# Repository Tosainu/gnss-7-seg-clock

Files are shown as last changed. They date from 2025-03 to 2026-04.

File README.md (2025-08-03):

# GNSS Seven-segment Clock

GNSS-powered, seven-segment table clock.



https://github.com/user-attachments/assets/9b2d0560-d879-4ddb-b99d-07a6e9839360

Full video: https://www.youtube.com/watch?v=Y1P_iDvq4bk

## Firmware

### Usage

Pre-build firmware files are available on the [release page](https://github.com/Tosainu/gnss-7-seg-clock/releases). Thanks to the RP2040 Bootrom, flashing the firmware requires no special tool. Connect the board to the PC using the USB-C cable, while holding the BOOT button (`SW2`). Once the `RPI-RP2` drive appears on the PC, copy `gnss-7-seg-clock.uf2` there. The board will automatically be rebooted as soon as it finishes writing to Flash.

- The board displays `--.--.--` until it obtains the time information.
- Press `SW3` to change the display contents:
    1. Time: `hh.mm.ss`
    2. Date: `YY.MM.DD`
    3. Configuring time zone (time offset): `[-]hh.mm`
        - `SW4`: + 30 min
        - `SW5`: - 30 min

### Build

The firmware is written in the [Rust][rust] programming language with the [Embassy][embassy] framework. In order to build the firmware, you first need to prepare the Rust toolchain. Please refer to the [official guide][rustup].

Next, install the linker helper [`flip-link`][flip-link]. Alternatively, remove [this line](https://github.com/Tosainu/gnss-7-seg-clock/blob/446c9426d9386b7eddf7218308c7567423a233c5/.cargo/config.toml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) to use the default linker.

    $ cargo install --locked flip-link

Lastly, run the command below to build the firmware. You can find the ELF file `./target/thumbv6m-none-eabi/release/gnss-7-seg-clock` afterward.

    $ cargo build --release

If the debug probe is attached to the board and [probe-rs][probe-rs] is installed on your PC, `cargo run` can be used to load firmware to the board.

    $ cargo run --release
    
    # to run test apps in crates/gnss-7-seg-clock/examples/
    $ cargo run --release --example gnss-uart-pipe

## Schematic and PCB

> [!IMPORTANT]
> I'm new to circuits and PCB designs. Any feedback and advice are welcome! (✿ゝ◡╹)ノ

I designed the Rev.A board with KiCad v8.0.8 (Linux/macOS) and their official libraries. You can find the KiCad project files in the [`hardware/`](./hardware/) directory. You can also find the rendered schematic (PDF) and Gerber files on the [release page](https://github.com/Tosainu/gnss-7-seg-clock/releases/tag/hardware%2Frev-a).




<sub>
Please do not take a close look at 43-44 pins of RP2040! (ignorable solder bridge)
</sub>

### Parts

> [!NOTE]
> Tolerances were set by just referring to several existing designs. Some of them might be insufficient or overkill.

| Reference | Value | Parts | Qty |
| --- | --- | --- | --: |
| `C1`, `C2`, `C4-C10`, `C14`, `C17-C19` | MLCC, 0.1uF, 10%, 6.3V, X5R, M1005 | | 13 |
| `C3`, `C11` | MLCC, 1uF, 20%, 6.3V, X5R, M1005 | | 2 |
| [`C12`, `C13`](#ldo-and-capacitors) | MLCC, 10uF, 10%, 6.3V, X7R, M2012 | | 2 |
| `C15`, `C16` | MLCC, 15pF, 5%, 50V, C0G/NP0, M1005 | | 2 |
| [`C20`](#rf-circuitry-for-max-m10s) | MLCC, 10000pF, 10%, 16V, X7R, M1005 | | 1 |
| [`C21`](#rf-circuitry-for-max-m10s) | MLCC, 47pF, 5%, 50V, C0G/NP0, M1005 | | 1 |
| [`D1`](#rf-circuitry-for-max-m10s) | Bidirectional TVS, M1005 | [Littelfuse PESD0402-140][PESD0402-140] | 1 |
| `D2-D7` | LED, M1005 | | 6 |
| `J1` | USB-C Receptacle | [GCT USB4105-GF-A](https://gct.co/connector/usb4105) | 1 |
| `J2` | SMA Receptacle, Edge Mount | [Molex 732511153][732511153] | 1 |
| `J3` | Pin header, 01x03, P2.54 mm | | 1 |
| [`L1`](#rf-circuitry-for-max-m10s) | Inductor, 27nH, 5%, M1005 | [Murata LQG15HS27NJ02D][LQG15HS27NJ02D] | 1 |
| [`R1-R3`](#driving-seven-segment-leds-with-fewer-pins) | Resistor, 2.2kOhm, 1%, 1/16W, M1005 | | 3 |
| `R4`, `R5`, `R12`, `R14-R16` | Resistor, 10kOhm, 1%, 1/16W, M1005 | | 6 |
| `R6`, `R7` | Resistor, 5.1kOhm, 1%, 1/16W, M1005 | | 2 |
| `R8`, `R9` | Resistor, 27Ohm, 1%, 1/16W, M1005 | | 2 |
| `R10`, `R13` | Resistor, 1kOhm, 1%, 1/16W, M1005 | | 2 |
| [`R11`](#rf-circuitry-for-max-m10s) | Resistor, 10Ohm, 5%, 1/4W, M1005 | | 1 |
| `R17-R22` | Resistor, 470Ohm, 1%, 1/16W, M1005 | | 6 |
| `SW1-SW5` | Tactile Switch | [C&K PTS810][PTS810] | 5 |
| [`U1-U6`](#seven-segment-leds) | 7-segment LED, Common-Anode, 3.81 mm | | 6 |
| [`U7-U9`](#driving-seven-segment-leds-with-fewer-pins) | 16-ch LED sink driver, SOIC-24W | [TI TLC5925IDWR][TLC5925] | 3 |
| `U10` | MCU | [Raspberry Pi RP2040][RP2040] | 1 |
| [`U11`](#ldo-and-capacitors) | LDO, 3.3V, 500 mA, SOT-23-5 | [TI TLV75533PDBVR][TLV755P] | 1 |
| `U12` | SQPI NOR Flash, 32M-bit, SOIC-8 | [Winbond W25Q32JVSS][W25Q32JV] | 1 |
| `U13` | GNSS Receiver | [u-blox MAX-M10S][MAX-M10] | 1 |
| `Y1` | Crystal, 12MHz | [Abracon ABM8-272-T3][ABM8-272-T3] | 1 |
| | GNSS Active Antenna | [u-blox ANN-MB5][ANN-MB5] | 1 |

### Seven-segment LEDs

`U1-U6` are seven-segment LEDs, the essential components in this design. While selecting them, I was surprised about the poor availability of seven-segment LEDs, especially the larger models (> 1″). I wanted to use [Kingbright SA15-11GWA][SA15-11GWA] initially. However, due to the availability and price, I selected [WENRUN LSD150BAG-101][LSD150BAG-101], even though I had to use a different store from other parts.

Unfortunately, LSD150BAG-101 is not a drop-in replacement for SA15-11GWA. They have a different pitch for the vertical direction: 40.64mm (SA15-11GWA) and 40.00mm (LSD150BAG-101). Since I wanted to have some flexibility in the design, I made the footprint that uses the oval pad so that can use both types of seven-segment LEDs.

footprint-7-seg

The forward voltage also has to be taken into account for `U1-U6`. Vf should be smaller than the USB VBUS. For instance, high-luminance types are not suitable in general.

### Driving Seven-segment LEDs with Fewer Pins

`U7`, `U8`, and `U9` are 16-ch shift registers specialized for the LED, [TI TLC5925IDWR](TLC5925). Thanks to this three-cascading configuration, it can drive six seven-segment LEDs (48x LED segments) only by five pins.

TLC5925 determines the output currents based on an external resistor between the `R-EXT` pin and `GND`. `R1`, `R2`, and `R3` are the current-set resistors for `U7`, `U8`, and `U9` respectively. With the 2.2kOhm resistor, the output would be (1.21 / 2,200) \* 18  = 9.9mA.

### LDO and Capacitors

`U11` is the 3.3V LDO, [TI TLV75533PDBVR](TLV755P) (TLV755P-series). I'm hoping it works nicely with an AC adapter/wall charger as well as a PC because of its good PSRR in wide-range frequencies.

`C12` and `C13` are the input and output capacitors for the LDO. According to the datasheet, TLV755P requires a 1uF+ input capacitor and a 0.47uF+ output capacitor while considering the DC bias characteristics of a capacitor. Based on this, I selected 10uF/6.3V MLCC.

### RF Circuitry for MAX-M10S

[sparkfun/SparkFun\_u-blox\_MAX-M10S][SparkFun-MAX-M10S] is very good material as well as the MAX-M10S Integration manual. For the RF part, I imitated SparkFun's board and filled in parts values based on the reference design mentioned in the integration manual. Here are the parts correspondences between this board and the MAX-M10S reference design:

| This board | Reference design | Use |
| --- | --- | --- |
| `C20` | `C14` |  RF Bias-T Capacitor |
| `C21` | `C18` | DC Block Capacitor[^dc-block-cap] |
| `L1` | `L3` | RF Bias-T Inductor |
| `R11` | `R8` | Antenna supervisor current limiter/shunt resistor |

`D1` is the ESD-protection TVS which is only in the SparkFun's board. Since I have no confidence in finding compatible parts, I used the same TVS [Littelfuse PESD0402-140][PESD0402-140] in this design.

[^dc-block-cap]: Apparently, this capacitor can be removed as my design doesn't have an external SAW filter. The built-in DC-block capacitor of the module is sufficient.

## Special Thanks - PCBWay

I would like to say a special thank you to [PCBWay](https://www.pcbway.com/) for reaching out and sponsoring my project. As part of the sponsorship, I had the opportunity to try their PCBA service. Overall I am very satisfied with the service and quality of the PCBs. Especially,

- Swift and kind support
    - I was surprised that they reviewed my design files very quickly and gave me a reply after about an hour from the order.
- Numerous customization options for PCB manufacturing
- Help Center
    - There are how-to specialized for KiCad such as [_"How to Generate Gerber and Drill Files in KiCad 8.0?"_](https://www.pcbway.com/helpcenter/generate_gerber/Generate_Gerber_file_from_Kicad.html) and [_"Generate Position File Centroid File(pick place) in Kicad"_](https://www.pcbway.com/helpcenter/design_instruction/Generate_Position_File_in_Kicad.html). They were very helpful when I generate design files for the order.
- Quality of PCBs
    - The board has RP2040 which is the 0.20 mm pitch IC but there were no major issues. One thing to note is the soldermask color: green would be the only choice for such boards according to their explanations and the document [_"Soldermask Issues - Soldermask bridge"_](https://www.pcbway.com/helpcenter/soldermask_issues/Soldermask_bridge.html).

250316-133125-DSC_8347

Note that I made some changes from the Rev.A design for this order, such as changing footprints to a non-HandSolder variant. If you're interested in about the design files I used to order, please refer to the [Rev.A2 release](https://github.com/Tosainu/gnss-7-seg-clock/releases/tag/hardware%2Frev-a2).

## License

The project is licensed under the [MIT](./LICENSE) license unless otherwise stated.

PCD design files, specifically the files under the [`hardware/`](./hardware/) directory are licensed under the [CC BY-SA 4.0](https://creativecommons.org/licenses/by-sa/4.0/) license. Please note that:
- Footprint files described below are made based on the [KiCad Footprint Libraries](https://gitlab.com/kicad/libraries/kicad-footprints) which is licensed under the [CC-BY-SA 4.0 license with exceptions](https://gitlab.com/kicad/libraries/kicad-footprints/-/blob/8.0.8/LICENSE.md?ref_type=tags).
    - [`Display_7Segment_1.5inch_P2.45mm.kicad_mod`](./hardware/gnss-7-seg-clock.pretty/Display_7Segment_1.5inch_P2.45mm.kicad_mod)
    - [`QFN-56-1EP_7x7mm_P0.4mm_EP3.2x3.2mm_HandSolder.kicad_mod`](./hardware/gnss-7-seg-clock.pretty/QFN-56-1EP_7x7mm_P0.4mm_EP3.2x3.2mm_HandSolder.kicad_mod)
    - [`SW_SPST_PTS810_HandSolder.kicad_mod`](./hardware/gnss-7-seg-clock.pretty/SW_SPST_PTS810_HandSolder.kicad_mod)
    - [`USB_C_Receptacle_GCT_USB4105-xx-A_16P_TopMnt_Horizontal_HandSolder.kicad_mod`](./hardware/gnss-7-seg-clock.pretty/USB_C_Receptacle_GCT_USB4105-xx-A_16P_TopMnt_Horizontal_HandSolder.kicad_mod)
- 3D model of ublox MAX module [`MAX (STEP-AP214).STEP`](./hardware/3d_models/MAX%20(STEP-AP214).STEP) is copied from [u-blox/3D-Step-Models-Library@92ce6ba0](https://github.com/u-blox/3D-Step-Models-Library/tree/92ce6ba04a1dacdbec4c5b9e0c032d87bb4d9fc0).

    > Copyright (C) u-blox
    >
    > u-blox reserves all rights in this deliverable (documentation, software, etc., hereafter “Deliverable”).
    >
    > u-blox grants you the right to use, copy, modify and distribute the Deliverable provided hereunder for any purpose without fee.
    >
    > THIS DELIVERABLE IS BEING PROVIDED "AS IS", WITHOUT ANY EXPRESS OR IMPLIED WARRANTY. IN PARTICULAR, NEITHER THE AUTHOR NOR U-BLOX MAKES ANY REPRESENTATION OR WARRANTY OF ANY KIND CONCERNING THE MERCHANTABILITY OF THIS DELIVERABLE OR ITS FITNESS FOR ANY PARTICULAR PURPOSE.
    >
    > In case you provide us a feedback or make a contribution in the form of a further development of the Deliverable (“Contribution”), u-blox will have the same rights as granted to you, namely to use, copy, modify and distribute the Contribution provided to us for any purpose without fee.

- Circuits around the MAX-M10S module on the schematic are made based on [sparkfun/SparkFun\_u-blox\_MAX-M10S][SparkFun-MAX-M10S] which is licensed under the [CC BY-SA 4.0](https://github.com/sparkfun/SparkFun_u-blox_MAX-M10S/blob/8e937406ba0f21e3afc8ca20ddeb06b088023951/LICENSE.md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) license for the hardware part.

This project is inspired by [Kello version 4](http://kair.us/projects/clock/v4/index.html).

[rust]: https://www.rust-lang.org/
[rustup]: https://www.rust-lang.org/tools/install
[embassy]: https://embassy.dev/
[flip-link]: https://github.com/knurling-rs/flip-link
[probe-rs]: https://probe.rs/

[RP2040]: https://www.raspberrypi.com/products/rp2040/
[LQG15HS27NJ02D]: https://www.murata.com/en-global/products/productdetail?partno=LQG15HS27NJ02%23
[LSD150BAG-101]: https://www.tme.eu/en/details/lsd150bag-101/7-segment-led-displays/wenrun/lsd150bag-101-01/
[PESD0402-140]: https://www.littelfuse.com/products/overvoltage-protection/polymer-esd-suppressors/pesd-protection-device/pesd/pesd0402-140
[PTS810]: https://www.ckswitches.com/products/switches/product-details/Tactile/PTS810/
[TLC5925]: https://www.ti.com/product/TLC5925
[TLV755P]: https://www.ti.com/product/TLV755P
[W25Q32JV]: https://www.winbond.com/hq/product/code-storage-flash-memory/serial-nor-flash/?__locale=en&partNo=W25Q32JV
[732511153]: https://www.molex.com/en-us/products/part-detail/732511153
[USB4105]: https://gct.co/connector/usb4105
[ABM8-272-T3]: https://abracon.com/datasheets/ABM8-272-T3.pdf
[ANN-MB5]: https://www.u-blox.com/en/product/ann-mb5-antenna
[MAX-M10]: https://www.u-blox.com/en/product/max-m10-series
[SA15-11GWA]: https://www.kingbrightusa.com/product.asp?catalog_name=LED&product_id=SA15-11GWA

[SparkFun-MAX-M10S]: https://github.com/sparkfun/SparkFun_u-blox_MAX-M10S

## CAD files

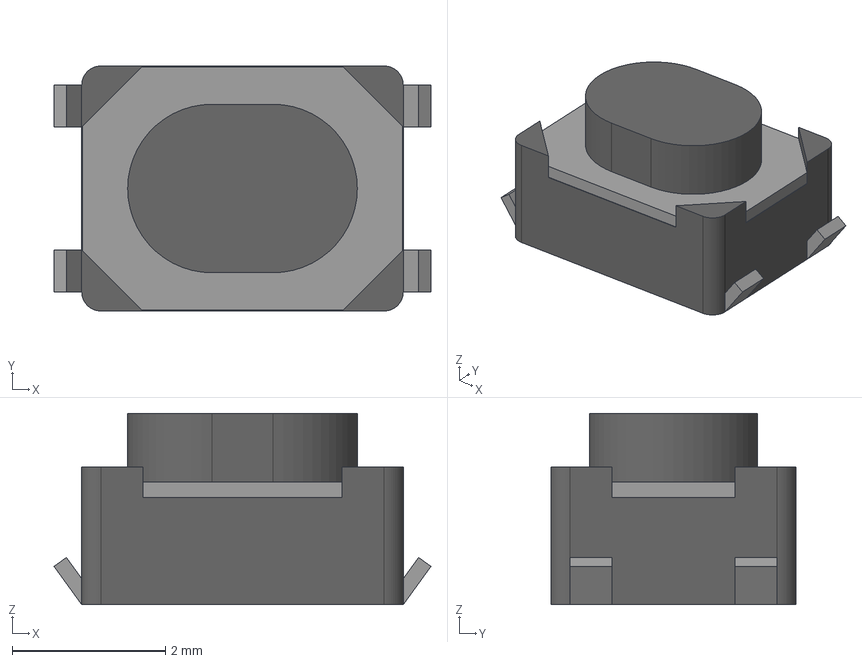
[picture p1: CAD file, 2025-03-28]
hardware/3d_models/PTS810.step
4.92 x 3.20 x 2.50 mm
Array (mirrored)
Pin x 2

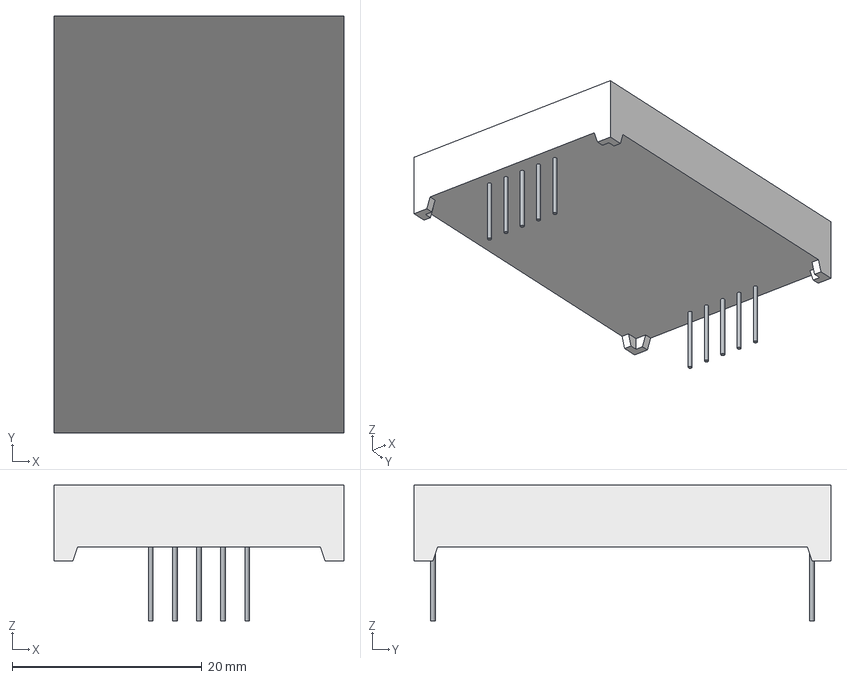
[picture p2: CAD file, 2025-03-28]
hardware/3d_models/LSD150BAG-101.step
30.6 x 44.0 x 14.3 mm
Plane
Plane001

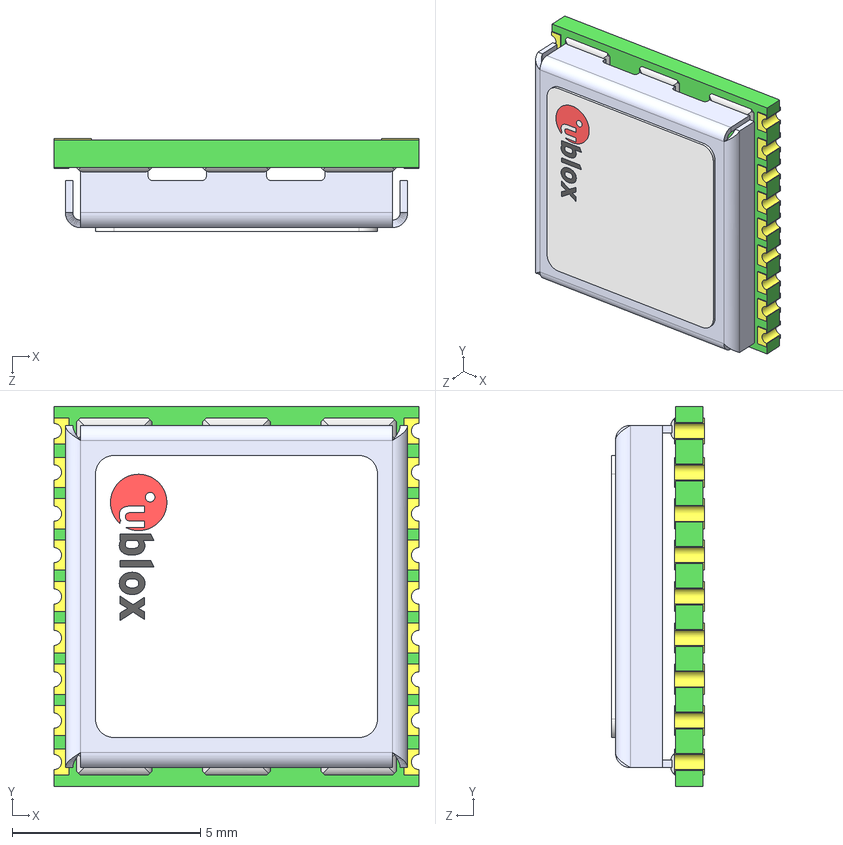
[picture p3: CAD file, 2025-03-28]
hardware/3d_models/MAX (STEP-AP214).STEP
9.70 x 10.1 x 2.47 mm
u-blox_MAX_label_Default
Shield
MAX_PCB

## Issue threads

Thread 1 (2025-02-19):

Strange things with RF

MuratovAS, 2025-02-19:
You clearly have problems with the RF cascade.
1. You put C21 (`DC BLOCK`), but for your `ublox` it is probably not required (check)
2. C20 and L1 should form a contour. Preventing leakage of a useful signal in power

P.S. I am not a radio engineer, I specialize in digital technique. So check my words.

A few schemes that I use as a reference:
https://github.com/dizcza/neo_m8p_board/blob/master/schematics.pdf
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

https://github.com/mlab-modules/GPS02
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

https://github.com/sparkfun/SparkFun_u-blox_MAX-M10S/blob/main/Hardware/SparkFun%20u-blox%20GNSS%20MAX-M10S.pdf
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

MuratovAS, 2025-02-19:
I build my cascade like this:
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

P.S. In a month I will have information about the quality of such a scheme

Tosainu, 2025-02-19:
Thank you for the information. That should be helpful for me since I'm not an RF expert or even an electronics engineer.

Regarding the DC BLOCK capacitor, I placed this capacitor because of the reference design mentioned in the MAX-M10S Integration Manual. I actually realized that most existing designs do not place such capacitors.
https://www.u-blox.com/sites/default/files/MAX-M10S_IntegrationManual_UBX-20053088.pdf

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

> 2. C20 and L1 should form a contour. Preventing leakage of a useful signal in power

Sorry but could you tell me a little more details on this point? I could not even find much difference with the designs you mentioned.

---

PS: I've just finished the first prototyping and I'm working on developing the firmware now. I verified that it could get a 3D fix at least. As you pointed out, there might be room to improve the signal quality though.

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

MuratovAS, 2025-02-20:
1. I found confirmation in the document.

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
https://content.u-blox.com/sites/default/files/MAX-M10S_DataSheet_UBX-20035208.pdf

Tosainu, 2025-02-20:
Thank you. And I might have figured out why Figure 38 has the DC Block capacitor. It's necessary when using an external SAW filter (F1), and needs to be placed in front of the filter.

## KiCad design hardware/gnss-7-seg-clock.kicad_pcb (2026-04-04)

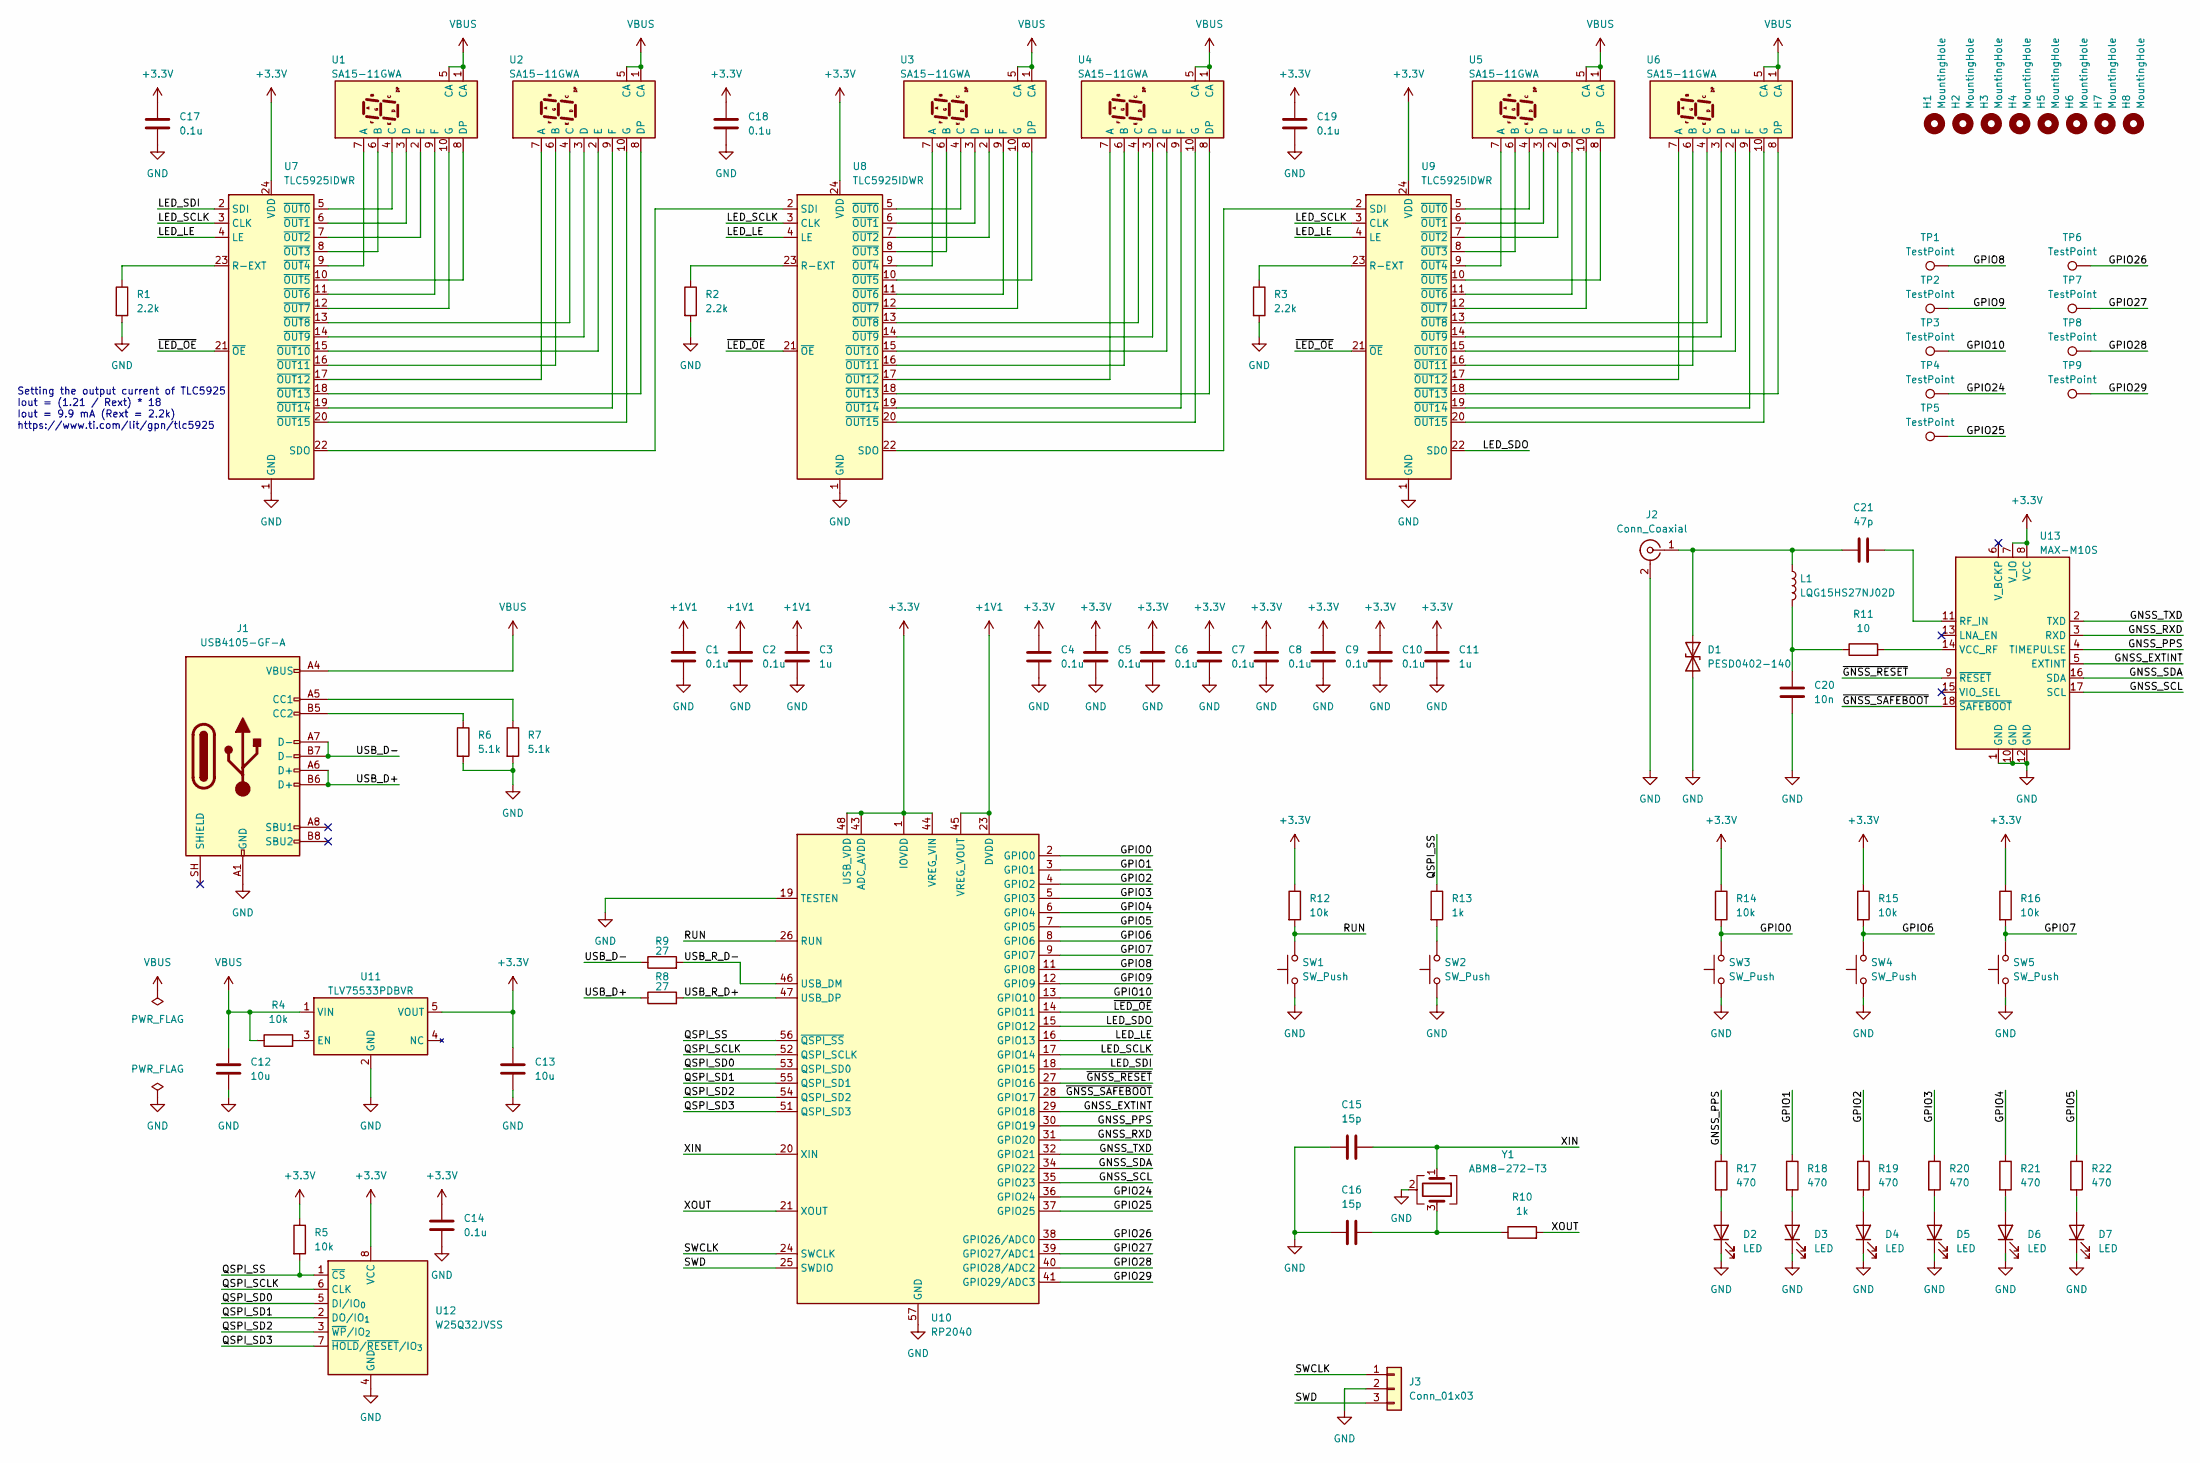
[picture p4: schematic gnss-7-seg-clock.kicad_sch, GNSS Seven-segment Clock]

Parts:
C1, C2, C4, C5, C6, C7, C8, C9, C10, C14, C17, C18, C19: 0.1u; C_0402_1005Metric_Pad0.74x0.62mm_HandSolder
C3, C11: 1u; C_0402_1005Metric_Pad0.74x0.62mm_HandSolder
C12, C13: 10u; C_0805_2012Metric_Pad1.18x1.45mm_HandSolder
C15, C16: 15p; C_0402_1005Metric_Pad0.74x0.62mm_HandSolder
C20: 10n; C_0402_1005Metric_Pad0.74x0.62mm_HandSolder
C21: 47p; C_0402_1005Metric_Pad0.74x0.62mm_HandSolder
D1: PESD0402-140; D_0402_1005Metric_Pad0.77x0.64mm_HandSolder
D2, D3, D4, D5, D6, D7: LED; LED_0402_1005Metric_Pad0.77x0.64mm_HandSolder
H1, H2, H3, H4, H5, H6, H7, H8: MountingHole; MountingHole_3.2mm_M3
J1: USB4105-GF-A; USB_C_Receptacle_GCT_USB4105-xx-A_16P_TopMnt_Horizontal_Han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
J2: Conn_Coaxial; SMA_Molex_73251-1153_EdgeMount_Horizontal
J3: Conn_01x03; PinHeader_1x03_P2.54mm_Vertical
L1: LQG15HS27NJ02D; L_0402_1005Metric_Pad0.77x0.64mm_HandSolder
R1, R2, R3: 2.2k; R_0402_1005Metric_Pad0.72x0.64mm_HandSolder
R4, R5, R12, R14, R15, R16: 10k; R_0402_1005Metric_Pad0.72x0.64mm_HandSolder
R6, R7: 5.1k; R_0402_1005Metric_Pad0.72x0.64mm_HandSolder
R8, R9: 27; R_0402_1005Metric_Pad0.72x0.64mm_HandSolder
R10, R13: 1k; R_0402_1005Metric_Pad0.72x0.64mm_HandSolder
R11: 10; R_0402_1005Metric_Pad0.72x0.64mm_HandSolder
R17, R18, R19, R20, R21, R22: 470; R_0402_1005Metric_Pad0.72x0.64mm_HandSolder
SW1, SW2, SW3, SW4, SW5: SW_Push; SW_SPST_PTS810_HandSolder
TP1, TP2, TP3, TP4, TP5, TP6, TP7, TP8, TP9: TestPoint; TestPoint_Pad_1.0x1.0mm
U1, U2, U3, U4, U5, U6: SA15-11GWA; Display_7Segment_1.5inch_P2.45mm
U7, U8, U9: TLC5925IDWR; SOIC-24W_7.5x15.4mm_P1.27mm
U10: RP2040; QFN-56-1EP_7x7mm_P0.4mm_EP3.2x3.2mm
U11: TLV75533PDBVR; TSOT-23-5_HandSoldering
U12: W25Q32JVSS; SOIC-8_5.3x5.3mm_P1.27mm
U13: MAX-M10S
Y1: ABM8-272-T3; Crystal_SMD_3225-4Pin_3.2x2.5mm_HandSoldering

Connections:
+1V1: C1.1, C2.1, C3.1, U10.23 (DVDD), U10.45 (VREG_VOUT), U10.50 (DVDD)
+3.3V: C4.1, C5.1, C6.1, C7.1, C8.1, C9.1, C10.1, C11.1, C13.1, C14.1, C17.1, C18.1, C19.1, R5.1, R12.1, R14.1, R15.1, R16.1, U7.24 (VDD), U8.24 (VDD), U9.24 (VDD), U10.1 (IOVDD), U10.10 (IOVDD), U10.22 (IOVDD), U10.33 (IOVDD), U10.42 (IOVDD), U10.43 (ADC_AVDD), U10.44 (VREG_VIN), U10.48 (USB_VDD), U10.49 (IOVDD), U11.5 (VOUT), U12.8 (VCC), U13.7 (V_IO), U13.8 (VCC)
/GNSS_EXTINT: U10.29 (GPIO18), U13.5 (EXTINT)
/GNSS_PPS: R17.1, U10.30 (GPIO19), U13.4 (TIMEPULSE)
/GNSS_RXD: U10.31 (GPIO20), U13.3 (RXD)
/GNSS_SCL: U10.35 (GPIO23), U13.17 (SCL)
/GNSS_SDA: U10.34 (GPIO22), U13.16 (SDA)
/GNSS_TXD: U10.32 (GPIO21), U13.2 (TXD)
/GPIO0: R14.2, SW3.2, U10.2 (GPIO0)
/GPIO1: R18.1, U10.3 (GPIO1)
/GPIO2: R19.1, U10.4 (GPIO2)
/GPIO3: R20.1, U10.5 (GPIO3)
/GPIO4: R21.1, U10.6 (GPIO4)
/GPIO5: R22.1, U10.7 (GPIO5)
/GPIO6: R15.2, SW4.2, U10.8 (GPIO6)
/GPIO7: R16.2, SW5.2, U10.9 (GPIO7)
/GPIO8: TP1.1, U10.11 (GPIO8)
/GPIO9: TP2.1, U10.12 (GPIO9)
/GPIO10: TP3.1, U10.13 (GPIO10)
/GPIO24: TP4.1, U10.36 (GPIO24)
/GPIO25: TP5.1, U10.37 (GPIO25)
/GPIO26: TP6.1, U10.38 (GPIO26/ADC0)
/GPIO27: TP7.1, U10.39 (GPIO27/ADC1)
/GPIO28: TP8.1, U10.40 (GPIO28/ADC2)
/GPIO29: TP9.1, U10.41 (GPIO29/ADC3)
/LED_LE: U7.4 (LE), U8.4 (LE), U9.4 (LE), U10.16 (GPIO13)
/LED_SCLK: U7.3 (CLK), U8.3 (CLK), U9.3 (CLK), U10.17 (GPIO14)
/LED_SDI: U7.2 (SDI), U10.18 (GPIO15)
/LED_SDO: U9.22 (SDO), U10.15 (GPIO12)
/QSPI_SCLK: U10.52 (QSPI_SCLK), U12.6 (CLK)
/QSPI_SD0: U10.53 (QSPI_SD0), U12.5 (DI/IO_{0})
/QSPI_SD1: U10.55 (QSPI_SD1), U12.2 (DO/IO_{1})
/QSPI_SD2: U10.54 (QSPI_SD2), U12.3 (~WP/IO_{2})
/QSPI_SD3: U10.51 (QSPI_SD3), U12.7 (~HOLD/~RESET/IO_{3})
/QSPI_SS: R5.2, R13.1, U10.56 (~QSPI_SS), U12.1 (~CS)
/RUN: R12.2, SW1.2, U10.26 (RUN)
/SWCLK: J3.1, U10.24 (SWCLK)
/SWD: J3.3, U10.25 (SWDIO)
/USB_D+: J1.A6 (D+), J1.B6 (D+), R8.1
/USB_D-: J1.A7 (D-), J1.B7 (D-), R9.1
/USB_R_D+: R8.2, U10.47 (USB_DP)
/USB_R_D-: R9.2, U10.46 (USB_DM)
/XIN: C15.2, U10.20 (XIN), Y1.1
/XOUT: R10.2, U10.21 (XOUT)
/~GNSS_RESET: U10.27 (GPIO16), U13.9 (~RESET)
/~GNSS_SAFEBOOT: U10.28 (GPIO17), U13.18 (~SAFEBOOT)
/~LED_OE: U7.21 (~OE), U8.21 (~OE), U9.21 (~OE), U10.14 (GPIO11)
GND: C1.2, C2.2, C3.2, C4.2, C5.2, C6.2, C7.2, C8.2, C9.2, C10.2, C11.2, C12.2, C13.2, C14.2, C15.1, C16.1, C17.2, C18.2, C19.2, C20.2, D1.2 (A2), D2.1 (K), D3.1 (K), D4.1 (K), D5.1 (K), D6.1 (K), D7.1 (K), J1.A1 (GND), J1.A12 (GND), J1.B1 (GND), J1.B12 (GND), J2.2 (Ext), J3.2, R1.2, R2.2, R3.2, R6.2, R7.2, SW1.1, SW2.1, SW3.1, SW4.1, SW5.1, U7.1 (GND), U8.1 (GND), U9.1 (GND), U10.19 (TESTEN), U10.57 (GND), U11.2 (GND), U12.4 (GND), U13.1 (GND), U13.10 (GND), U13.12 (GND), Y1.2 (G), Y1.4 (G)
unnamed: C16.2, R10.1, Y1.3
unnamed: C20.1, L1.2, R11.1
unnamed: C21.1, D1.1 (A1), J2.1 (In), L1.1
unnamed: D2.2 (A), R17.2
unnamed: D3.2 (A), R18.2
unnamed: D4.2 (A), R19.2
unnamed: D5.2 (A), R20.2
unnamed: D6.2 (A), R21.2
unnamed: D7.2 (A), R22.2
unnamed: J1.A5 (CC1), R7.1
unnamed: J1.B5 (CC2), R6.1
unnamed: R13.2, SW2.2
unnamed: U1.7 (A), U7.9 (~OUT4)
unnamed: U1.6 (B), U7.8 (~OUT3)
unnamed: U1.4 (C), U7.5 (~OUT0)
unnamed: U1.3 (D), U7.6 (~OUT1)
unnamed: U1.8 (DP), U7.10 (~OUT5)
unnamed: U1.2 (E), U7.7 (~OUT2)
unnamed: U1.9 (F), U7.11 (~OUT6)
unnamed: U1.10 (G), U7.12 (~OUT7)
unnamed: U2.7 (A), U7.17 (~OUT12)
unnamed: U2.6 (B), U7.16 (~OUT11)
unnamed: U2.4 (C), U7.13 (~OUT8)
unnamed: U2.3 (D), U7.14 (~OUT9)
unnamed: U2.8 (DP), U7.18 (~OUT13)
unnamed: U2.2 (E), U7.15 (~OUT10)
unnamed: U2.9 (F), U7.19 (~OUT14)
unnamed: U2.10 (G), U7.20 (~OUT15)
unnamed: U3.7 (A), U8.9 (~OUT4)
unnamed: U3.6 (B), U8.8 (~OUT3)
unnamed: U3.4 (C), U8.5 (~OUT0)
unnamed: U3.3 (D), U8.6 (~OUT1)
unnamed: U3.8 (DP), U8.10 (~OUT5)
unnamed: U3.2 (E), U8.7 (~OUT2)
unnamed: U3.9 (F), U8.11 (~OUT6)
unnamed: U3.10 (G), U8.12 (~OUT7)
unnamed: U4.7 (A), U8.17 (~OUT12)
unnamed: U4.6 (B), U8.16 (~OUT11)
unnamed: U4.4 (C), U8.13 (~OUT8)
unnamed: U4.3 (D), U8.14 (~OUT9)
unnamed: U4.8 (DP), U8.18 (~OUT13)
unnamed: U4.2 (E), U8.15 (~OUT10)
unnamed: U4.9 (F), U8.19 (~OUT14)
unnamed: U4.10 (G), U8.20 (~OUT15)
unnamed: U5.7 (A), U9.9 (~OUT4)
unnamed: U5.6 (B), U9.8 (~OUT3)
unnamed: U5.4 (C), U9.5 (~OUT0)
unnamed: U5.3 (D), U9.6 (~OUT1)
unnamed: U5.8 (DP), U9.10 (~OUT5)
unnamed: U5.2 (E), U9.7 (~OUT2)
unnamed: U5.9 (F), U9.11 (~OUT6)
unnamed: U5.10 (G), U9.12 (~OUT7)
unnamed: U6.7 (A), U9.17 (~OUT12)
unnamed: U6.6 (B), U9.16 (~OUT11)
unnamed: U6.4 (C), U9.13 (~OUT8)
unnamed: U6.3 (D), U9.14 (~OUT9)
unnamed: U6.8 (DP), U9.18 (~OUT13)
unnamed: U6.2 (E), U9.15 (~OUT10)
unnamed: U6.9 (F), U9.19 (~OUT14)
unnamed: U6.10 (G), U9.20 (~OUT15)
unnamed: R1.1, U7.23 (R-EXT)
unnamed: U7.22 (SDO), U8.2 (SDI)
unnamed: R2.1, U8.23 (R-EXT)
unnamed: U8.22 (SDO), U9.2 (SDI)
unnamed: R3.1, U9.23 (R-EXT)
unnamed: R4.2, U11.3 (EN)
unnamed: C21.2, U13.11 (RF_IN)
unnamed: R11.2, U13.14 (VCC_RF)
VBUS: C12.1, J1.A4 (VBUS), J1.A9 (VBUS), J1.B4 (VBUS), J1.B9 (VBUS), R4.1, U1.1 (CA), U1.5 (CA), U2.1 (CA), U2.5 (CA), U3.1 (CA), U3.5 (CA), U4.1 (CA), U4.5 (CA), U5.1 (CA), U5.5 (CA), U6.1 (CA), U6.5 (CA), U11.1 (VIN)

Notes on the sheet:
Setting the output current of TLC5925 Iout = (1.21 / Rext) * 18 Iout = 9.9 mA (Rext = 2.2k) https://www.ti.com/lit/gpn/tlc5925

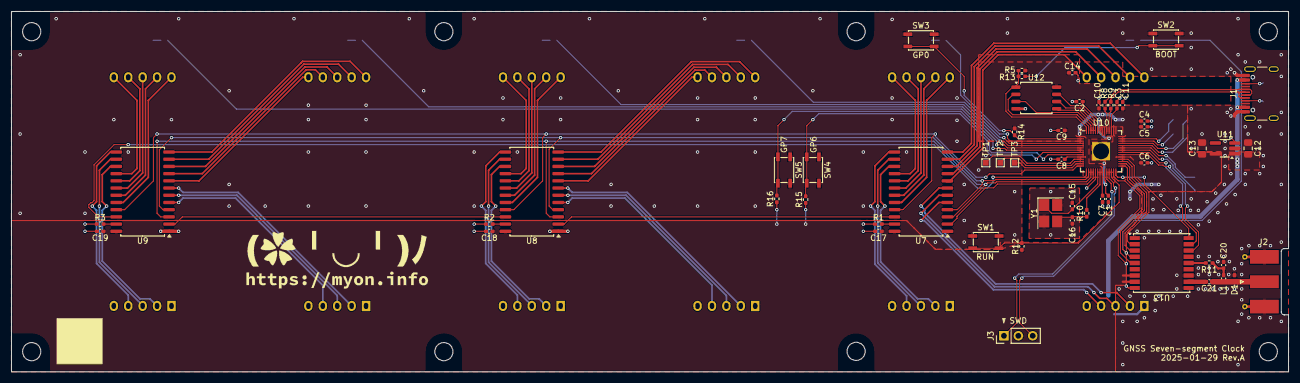
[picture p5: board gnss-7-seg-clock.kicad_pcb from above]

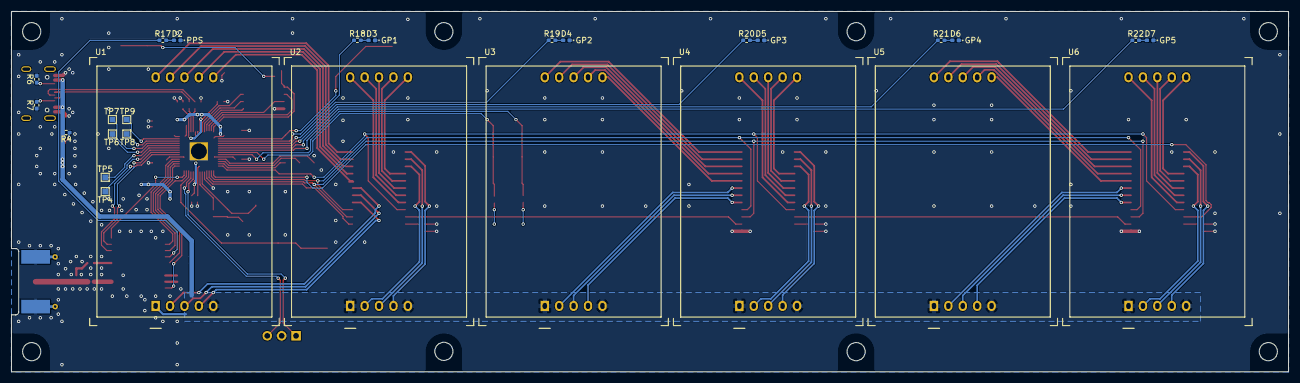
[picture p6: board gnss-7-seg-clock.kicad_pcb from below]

Board: 2 copper layers, 225.0 x 63.5 mm, 90 parts (27 on the bottom side), 117 nets.

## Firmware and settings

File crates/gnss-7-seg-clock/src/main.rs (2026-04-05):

#![no_std]
#![no_main]

use embassy_executor::Spawner;
use embassy_rp::dma;
use embassy_rp::flash;
use embassy_rp::gpio;
use embassy_rp::i2c;
use embassy_rp::peripherals::{DMA_CH0, I2C1, UART1};
use embassy_rp::spi;
use embassy_rp::uart;
use embassy_sync::{
    blocking_mutex::raw::{RawMutex, ThreadModeRawMutex},
    channel::Channel,
};
use static_cell::StaticCell;

use chrono::{Datelike, FixedOffset, NaiveDate, NaiveTime, Timelike};

use gnss_7_seg_clock::{
    display::{self, Display},
    events::*,
    flash::NonVolatileConfig,
    max_m10s::{Event as MaxM10sEvent, MaxM10s},
};

use {defmt_rtt as _, panic_probe as _};

embassy_rp::bind_interrupts!(struct Irqs {
    DMA_IRQ_0 => dma::InterruptHandler<DMA_CH0>;
    I2C1_IRQ => i2c::InterruptHandler<I2C1>;
    UART1_IRQ => uart::BufferedInterruptHandler<UART1>;
});

type MaxM10sEventChannel = Channel<ThreadModeRawMutex, MaxM10sEvent, 8>;

//
//     +- A -+
//     F     B
//     +- G -+
//     E     C
//     +- D -+
//
//    GFpABEDC
const TABLE: [u8; 10] = [
    0b01011111_u8, // '0'
    0b00001001_u8, // '1'
    0b10011110_u8, // '2'
    0b10011011_u8, // '3'
    0b11001001_u8, // '4'
    0b11010011_u8, // '5'
    0b11010111_u8, // '6'
    0b00011001_u8, // '7'
    0b11011111_u8, // '8'
    0b11011011_u8, // '9'
];

#[allow(dead_code)]
const MASK_DP: u8 = 0b00100000;

// "--.--.--"
const PATTERN_NO_TIME: display::Payload = display::Payload([
    0b10000000_u8,
    0b10000000_u8,
    0b10100000_u8,
    0b10000000_u8,
    0b10100000_u8,
    0b10000000_u8,
]);

fn date_to_display_payload(date: NaiveDate) -> display::Payload {
    display::Payload([
        TABLE[date.day() as usize % 10],
        TABLE[date.day() as usize / 10 % 10],
        TABLE[date.month() as usize % 10] | MASK_DP,
        TABLE[date.month() as usize / 10 % 10],
        TABLE[date.year() as usize % 10] | MASK_DP,
        TABLE[date.year() as usize / 10 % 10],
    ])
}

fn time_to_display_payload(time: NaiveTime) -> display::Payload {
    display::Payload([
        TABLE[time.second() as usize % 10],
        TABLE[time.second() as usize / 10 % 10],
        TABLE[time.minute() as usize % 10] | MASK_DP,
        TABLE[time.minute() as usize / 10 % 10],
        TABLE[time.hour() as usize % 10] | MASK_DP,
        TABLE[time.hour() as usize / 10 % 10],
    ])
}

fn u32_to_display_payload(value: u32) -> display::Payload {
    let mut arr = [
        TABLE[value as usize % 10],
        TABLE[value as usize / 10 % 10],
        TABLE[value as usize / 100 % 10],
        TABLE[value as usize / 1000 % 10],
        TABLE[value as usize / 10000 % 10],
        TABLE[value as usize / 100000 % 10],
    ];
    arr[3] |= MASK_DP;
    if value < 100_000 {
        arr[5] = 0;
    }
    if value < 10_000 {
        arr[4] = 0;
    }
    display::Payload(arr)
}

const FLASH_SIZE: usize = 4 * 1024 * 1024; // W25Q32JVSS
const ADDR_OFFSET: u32 = (FLASH_SIZE - flash::ERASE_SIZE) as u32;

#[derive(Copy, Clone, Default, PartialEq, serde::Serialize, serde::Deserialize, defmt::Format)]
struct Config {
    time_zone_secs: i32,
}

impl Config {
    fn time_zone(&self) -> FixedOffset {
        FixedOffset::east_opt(self.time_zone_secs).unwrap()
    }
}

#[derive(Copy, Clone, PartialEq, defmt::Format)]
enum DisplayMode {
    Time,
    Date,
    Velocity,
    ConfigTimeZone,
}

impl DisplayMode {
    fn next_state(&self) -> DisplayMode {
        match self {
            DisplayMode::Time => DisplayMode::Date,
            DisplayMode::Date => DisplayMode::Velocity,
            DisplayMode::Velocity => DisplayMode::ConfigTimeZone,
            DisplayMode::ConfigTimeZone => DisplayMode::Time,
        }
    }
}

#[embassy_executor::main]
async fn main(spawner: Spawner) {
    let p = embassy_rp::init(Default::default());

    defmt::info!("Hello World!");

    let mut nvcfg = NonVolatileConfig::<_, _, FLASH_SIZE, ADDR_OFFSET, 512>::new(p.FLASH);
    let mut cfg: Config = defmt::unwrap!(nvcfg.read_or_default());
    defmt::info!("{}", cfg);

    let sw3 = gpio::Input::new(p.PIN_0, gpio::Pull::None);
    let sw4 = gpio::Input::new(p.PIN_6, gpio::Pull::None);
    let sw5 = gpio::Input::new(p.PIN_7, gpio::Pull::None);

    let mut leds = [
        gpio::Output::new(p.PIN_1, gpio::Level::Low),
        gpio::Output::new(p.PIN_2, gpio::Level::Low),
        gpio::Output::new(p.PIN_3, gpio::Level::Low),
        gpio::Output::new(p.PIN_4, gpio::Level::Low),
        gpio::Output::new(p.PIN_5, gpio::Level::Low),
    ];

    let _spi1_rx = gpio::Input::new(p.PIN_12, gpio::Pull::Down);
    let mut display = Display::new(
        p.SPI1, p.PIN_14, p.PIN_15, p.DMA_CH0, p.PIN_11, p.PIN_13, Irqs,
    );

    display.shift(&PATTERN_NO_TIME).await;
    display.refresh().await;
    display.output(true);

    let _uart1_tx = gpio::Input::new(p.PIN_20, gpio::Pull::Up);
    let mut max_m10s_pps = gpio::Input::new(p.PIN_19, gpio::Pull::Down);
    let max_m10s = {
        static UART1_BUF_RX: StaticCell<[u8; 1024]> = StaticCell::new();
        MaxM10s::new(
            p.UART1,
            p.PIN_21,
            UART1_BUF_RX.init([0; 1024]).as_mut_slice(),
            p.I2C1,
            p.PIN_23,
            p.PIN_22,
            p.PIN_16,
            p.PIN_18,
            Irqs,
        )
    };

    static MAX_M10S_EVENT_CHANNEL: MaxM10sEventChannel = MaxM10sEventChannel::new();

    spawner.spawn(defmt::unwrap!(task_max_m10s(
        max_m10s,
        &MAX_M10S_EVENT_CHANNEL
    )));

    max_m10s_pps.wait_for_low().await;

    let mut mode = DisplayMode::Time;
    let mut es = EventSources::new(
        MAX_M10S_EVENT_CHANNEL.receiver(),
        sw3,
        sw4,
        sw5,
        max_m10s_pps,
    );

    loop {
        defmt::info!("mode: {}", mode);
        set_leds(&mut leds, mode);
        match mode {
            DisplayMode::Time => handle_mode_time(&mut es, &cfg, &mut display).await,
            DisplayMode::Date => handle_mode_date(&mut es, &cfg, &mut display).await,
            DisplayMode::Velocity => handle_mode_velocity(&mut es, &cfg, &mut display).await,
            DisplayMode::ConfigTimeZone => {
                let t = handle_mode_config_time_zone(&mut es, &cfg, &mut display).await;
                if t != cfg.time_zone_secs {
                    cfg.time_zone_secs = t;
                    defmt::unwrap!(nvcfg.write(&cfg));
                }
            }
        }
        mode = mode.next_state();
    }
}

fn set_leds(leds: &mut [gpio::Output<'_>; 5], mode: DisplayMode) {
    let bits = match mode {
        DisplayMode::Time => 0b0_0001_u8,
        DisplayMode::Date => 0b0_0010_u8,
        DisplayMode::Velocity => 0b0_0011_u8,
        DisplayMode::ConfigTimeZone => 0b1_0001_u8,
    };
    leds[0].set_level((bits & 0b1_0000 > 0).into());
    leds[1].set_level((bits & 0b0_1000 > 0).into());
    leds[2].set_level((bits & 0b0_0100 > 0).into());
    leds[3].set_level((bits & 0b0_0010 > 0).into());
    leds[4].set_level((bits & 0b0_0001 > 0).into());
}

async fn handle_mode_time<R: RawMutex, Spi: spi::Instance, const N: usize>(
    es: &mut EventSources<'_, R, N>,
    cfg: &Config,
    display: &mut Display<'_, Spi>,
) {
    if let Some(datetime) = es.datetime {
        let t = datetime + cfg.time_zone();
        display.shift(&time_to_display_payload(t.time())).await;
        display.refresh().await;
        if let Some(datetime_next_pulse) = es.datetime_next_pulse {
            let t_next = datetime_next_pulse + cfg.time_zone();
            display.shift(&time_to_display_payload(t_next.time())).await;
        }
    } else {
        display.shift(&PATTERN_NO_TIME).await;
        display.refresh().await;
    }

    loop {
        match es.wait().await {
            Event::DateTimeAndVelocity { datetime, .. } => {
                if es.datetime_next_pulse.is_none() && datetime.nanosecond() == 0 {
                    let t = datetime + cfg.time_zone();
                    display.shift(&time_to_display_payload(t.time())).await;
                    display.refresh().await;
                }
            }
            Event::DateTimeNextPulse(datetime) => {
                let t = datetime + cfg.time_zone();
                display.shift(&time_to_display_payload(t.time())).await;
            }
            Event::TimePulse => {
                display.refresh().await;
            }
            Event::Sw3Pressed => return,
            _ => (),
        }
    }
}

async fn handle_mode_date<R: RawMutex, Spi: spi::Instance, const N: usize>(
    es: &mut EventSources<'_, R, N>,
    cfg: &Config,
    display: &mut Display<'_, Spi>,
) {
    if let Some(datetime) = es.datetime {
        let t = datetime + cfg.time_zone();
        display.shift(&date_to_display_payload(t.date())).await;
        display.refresh().await;
        if let Some(datetime_next_pulse) = es.datetime_next_pulse {
            let t_next = datetime_next_pulse + cfg.time_zone();
            display.shift(&date_to_display_payload(t_next.date())).await;
        }
    } else {
        display.shift(&PATTERN_NO_TIME).await;
        display.refresh().await;
    }

    loop {
        match es.wait().await {
            Event::DateTimeAndVelocity { datetime, .. } => {
                if es.datetime_next_pulse.is_none() && datetime.nanosecond() == 0 {
                    let t = datetime + cfg.time_zone();
                    display.shift(&date_to_display_payload(t.date())).await;
                    display.refresh().await;
                }
            }
            Event::DateTimeNextPulse(datetime) => {
                let t = datetime + cfg.time_zone();
                display.shift(&date_to_display_payload(t.date())).await;
            }
            Event::TimePulse => {
                display.refresh().await;
            }
            Event::Sw3Pressed => return,
            _ => (),
        }
    }
}

async fn handle_mode_velocity<R: RawMutex, Spi: spi::Instance, const N: usize>(
    es: &mut EventSources<'_, R, N>,
    _cfg: &Config,
    display: &mut Display<'_, Spi>,
) {
    if let Some(ground_speed_meter_hour) = es.ground_speed_meter_hour {
        display
            .shift(&u32_to_display_payload(ground_speed_meter_hour))
            .await;
        display.refresh().await;
    } else {
        display.shift(&PATTERN_NO_TIME).await;
        display.refresh().await;
    }

    loop {
        match es.wait().await {
            Event::DateTimeAndVelocity {
                ground_speed_meter_hour,
                ..
            } => {
                display
                    .shift(&u32_to_display_payload(ground_speed_meter_hour))
                    .await;
                display.refresh().await;
            }
            Event::Sw3Pressed => return,
            _ => (),
        }
    }
}

async fn handle_mode_config_time_zone<R: RawMutex, Spi: spi::Instance, const N: usize>(
    es: &mut EventSources<'_, R, N>,
    cfg: &Config,
    display: &mut Display<'_, Spi>,
) -> i32 {
    let mut time_zone_secs = cfg.time_zone_secs;
    'outer: loop {
        let hour = time_zone_secs / 60 / 60;
        let min = (time_zone_secs / 60 % 60).unsigned_abs();
        let payload = display::Payload([
            TABLE[min as usize % 10],
            TABLE[min as usize / 10 % 10],
            TABLE[hour.unsigned_abs() as usize % 10] | MASK_DP,
            TABLE[hour.unsigned_abs() as usize / 10 % 10],
            if time_zone_secs.is_negative() {
                0b10000000_u8
            } else {
                0b00000000_u8
            },
            0,
        ]);
        display.shift(&payload).await;
        display.refresh().await;

        time_zone_secs = 'inner: loop {
            match es.wait().await {
                Event::Sw3Pressed => break 'outer time_zone_secs,
                Event::Sw4Pressed => break 'inner (time_zone_secs + 30 * 60).min(24 * 60 * 60),
                Event::Sw5Pressed => break 'inner (time_zone_secs - 30 * 60).max(-24 * 60 * 60),
                _ => (),
            }
        };
    }
}

#[embassy_executor::task]
async fn task_max_m10s(
    mut max_m10s: MaxM10s<'static, I2C1>,
    channel: &'static MaxM10sEventChannel,
) {
    max_m10s.run(channel.sender()).await;
}

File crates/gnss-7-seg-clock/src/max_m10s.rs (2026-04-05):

use embassy_futures::select::*;
use embassy_rp::{Peri, gpio, i2c, interrupt::typelevel::Binding, uart};
use embassy_sync::{blocking_mutex::raw::RawMutex, channel::Sender};
use embassy_time::{Duration, Instant, Timer};
use embedded_io_async::Read;

use chrono::{Datelike, NaiveDate, NaiveDateTime, NaiveTime, TimeDelta, Timelike};

use ubx::{UbxFrame, UbxStream};

const MAX_M10S_I2C_ADDRESS: u16 = 0x42;

const GPS_EPOCH: NaiveDateTime = NaiveDate::from_ymd_opt(1980, 1, 6)
    .unwrap()
    .and_time(NaiveTime::MIN);

pub struct MaxM10s<'d, I2c>
where
    I2c: i2c::Instance,
{
    uart: uart::BufferedUartRx,
    i2c: i2c::I2c<'d, I2c, i2c::Async>,
    gpio_nreset: gpio::Output<'d>,
    gpio_extint: gpio::Input<'d>,
}

#[derive(Copy, Clone, Debug, PartialEq, defmt::Format)]
enum State {
    PowerCycle,
    Setup,
    Ready,
}

pub enum Event {
    DateTimeAndVelocity {
        datetime: NaiveDateTime,
        ground_speed_meter_hour: u32,
    },
    DateTimeNextPulse(NaiveDateTime),
}

impl<'d, I2c> MaxM10s<'d, I2c>
where
    I2c: i2c::Instance,
{
    #[allow(clippy::too_many_arguments)]
    pub fn new<Uart: uart::Instance>(
        uart: Peri<'d, Uart>,
        uart_rx: Peri<'d, impl uart::RxPin<Uart>>,
        uart_rx_buffer: &'d mut [u8],
        i2c: Peri<'d, I2c>,
        i2c_scl: Peri<'d, impl i2c::SclPin<I2c>>,
        i2c_sda: Peri<'d, impl i2c::SdaPin<I2c>>,
        gpio_nreset: Peri<'d, impl gpio::Pin>,
        gpio_extint: Peri<'d, impl gpio::Pin>,
        irq: impl Binding<Uart::Interrupt, uart::BufferedInterruptHandler<Uart>>
        + Binding<I2c::Interrupt, i2c::InterruptHandler<I2c>>
        + 'd,
    ) -> Self {
        let uart_config = {
            let mut c = uart::Config::default();
            c.baudrate = 115200;
            c.parity = uart::Parity::ParityNone;
            c.stop_bits = uart::StopBits::STOP1;
            c
        };

        Self {
            uart: uart::BufferedUartRx::new(uart, irq, uart_rx, uart_rx_buffer, uart_config),
            i2c: i2c::I2c::new_async(i2c, i2c_scl, i2c_sda, irq, i2c::Config::default()),
            gpio_nreset: gpio::Output::new(gpio_nreset, gpio::Level::Low),
            gpio_extint: gpio::Input::new(gpio_extint, gpio::Pull::Up),
        }
    }

    pub async fn run<M: RawMutex, const N: usize>(&mut self, sender: Sender<'_, M, Event, N>) {
        let mut state = State::PowerCycle;
        loop {
            let next_state = match state {
                State::PowerCycle => self.do_power_cycle().await,
                State::Setup => self.do_setup().await,
                State::Ready => self.do_receive_ubx(&sender).await,
            };
            if next_state != state {
                defmt::info!("MAX-M10S: {} -> {}", state, next_state);
                state = next_state;
            }
        }
    }

    async fn do_power_cycle(&mut self) -> State {
        self.gpio_nreset.set_low();
        Timer::after_millis(500).await;
        self.gpio_nreset.set_high();
        State::Setup
    }

    async fn do_setup(&mut self) -> State {
        let ubx_cfg_valset_frame = {
            let mut frame = [
                0xb5, 0x62, // header
                0x06, 0x8a, // id/class (=UBX-CFG-VALSET)
                0x00, 0x00, // length
                // payload begin
                0x00, // version
                0x01, // layers (=ram)
                0x00, 0x00, // reserved
                0x01, 0x00, 0xa2, 0x10, 0x01, // CFG-TXREADY-ENABLED (=true)
                0x02, 0x00, 0xa2, 0x10, 0x01, // CFG-TXREADY-POLARIT (=true=low-active)
                0x03, 0x00, 0xa2, 0x20, 0x05, // CFG-TXREADY-PIN (=5=EXTINT)
                0x04, 0x00, 0xa2, 0x30, 0x01, 0x00, // CFG-TXREADY-THRESHOLD (=8/8)
                0x05, 0x00, 0xa2, 0x20, 0x00, // CFG-TXREADY-INTERFACE (=0=I2C)
                0x01, 0x00, 0x21, 0x30, 0xc8, 0x00, // CFG-RATE-MEAS (=200 ms/5 Hz)
                0x07, 0x00, 0x91, 0x20, 0x01, // CFG-MSGOUT-UBX_NAV_PVT_UART1 (=1)
                0x7e, 0x01, 0x91, 0x20, 0x01, // CFG-MSGOUT-UBX_TIM_TP_UART1 (=1)
                0x01, 0x00, 0x71, 0x10, 0x01, // CFG-I2CINPROT-UBX (=1)
                0x02, 0x00, 0x71, 0x10, 0x00, // CFG-I2CINPROT-NMEA (=0)
                0x01, 0x00, 0x72, 0x10, 0x01, // CFG-I2COUTPROT-UBX (=1)
                0x02, 0x00, 0x72, 0x10, 0x00, // CFG-I2COUTPROT-NMEA (=0)
                0x01, 0x00, 0x73, 0x10, 0x00, // CFG-UART1INPROT-UBX (=0)
                0x02, 0x00, 0x73, 0x10, 0x00, // CFG-UART1INPROT-NMEA (=0)
                0x01, 0x00, 0x74, 0x10, 0x01, // CFG-UART1OUTPROT-UBX (=1)
                0x02, 0x00, 0x74, 0x10, 0x00, // CFG-UART1OUTPROT-NMEA (=0)
                // CFG-UART1-BAUDRATE (=115200)
                0x01, 0x00, 0x52, 0x40, 0x00, 0xc2, 0x01, 0x00,
                // payload end
                0x00, // ck_a
                0x00, // ck_b
            ];
            let len = frame.len() as u16 - 8;
            frame[4..6].copy_from_slice(&len.to_le_bytes());
            (frame[frame.len() - 2], frame[frame.len() - 1]) =
                ubx::checksum(&frame[2..frame.len() - 2]);
            frame
        };

        let t = Instant::now();
        while let Err(e) = self
            .i2c
            .write_async(MAX_M10S_I2C_ADDRESS, ubx_cfg_valset_frame)
            .await
        {
            defmt::debug!("{}", e);
            if Instant::now() > t + Duration::from_secs(5) {
                defmt::warn!("I2C bus or device not ready");
                return State::PowerCycle;
            }
            Timer::after_millis(100).await;
        }

        let mut buf = UbxStream::<512>::new();
        'outer: loop {
            if let Either::Second(..) =
                select(self.gpio_extint.wait_for_low(), Timer::after_secs(1)).await
            {
                defmt::warn!("EXTINT pin (TX_READY) is not being asserted");
                return State::PowerCycle;
            }

            let mut len = [0; 2];
            if let Err(e) = self
                .i2c
                .write_read_async(MAX_M10S_I2C_ADDRESS, [0xfd_u8], &mut len)
                .await
            {
                defmt::warn!("I2C operation failed ({})", e);
                return State::PowerCycle;
            }

            let len = u16::from_be_bytes(len) as usize;
            defmt::debug!("len = {}", len);

            if let Err(e) = self
                .i2c
                .read_async(MAX_M10S_I2C_ADDRESS, &mut buf.buf_unused_mut()[..len])
                .await
            {
                defmt::warn!("I2C operation failed ({})", e);
                return State::PowerCycle;
            }

            buf.commit(len);
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

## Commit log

2025-01-29 Hardware Rev.A
    [LSD150.step, gnss-7-seg-clock.kicad_pcb, gnss-7-seg-clock.kicad_sch]
2025-01-31 Reduce output current of TLC5925 (22 mA -> 9.9 mA)
    It was too high for LSD150BAG-101.
    [gnss-7-seg-clock.kicad_pcb, gnss-7-seg-clock.kicad_sch]
2025-02-09 Add led checkout program
2025-02-10 Rename the file because defmt doesn't like such a name
    https://github.com/knurling-rs/defmt/issues/853
    [seven-seg-flash.rs]
2025-02-12 Add MAX-M10S I2C checkout program
2025-02-20 Fix the issue about printing `nmea::Error` with defmt
2025-02-20 Use SW3 to switch Date and Time
2025-03-28 Update 3D model of components
    [LSD150.step, LSD150BAG-101.step, MAX (STEP-AP214).STEP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]
2025-03-29 Re-save project with KiCad 9.0.0
    [gnss-7-seg-clock.kicad_pcb, gnss-7-seg-clock.kicad_sch]
2025-03-29 Update W25Q32JVSS footprint
    see also: https://gitlab.com/kicad/libraries/kicad-footprint-generator/-/merge_requests/1384
    [gnss-7-seg-clock.kicad_pcb, gnss-7-seg-clock.kicad_sch]
2025-03-29 Fix ERC
    [gnss-7-seg-clock.kicad_pcb, gnss-7-seg-clock.kicad_sch]
2025-04-12 Indicate the current `DisplayMode` by LEDs
2025-07-02 Cache the latest time (#24)
    This fixes regressin introduced in b24db0d2412d50fd361581d2e64102bfcc1be36a
    [events.rs]
2025-08-11 Rework kicad CI
2025-08-11 Re-save project with KiCad 9.0.3
    [gnss-7-seg-clock.kicad_pcb]
2025-09-05 Bump kicad/kicad from 9.0.3 to 9.0.4 (#30)
    Bumps [kicad/kicad](https://gitlab.com/kicad/kicad-ci/kicad-cli-docker) from 9.0.3 to 9.0.4.
    - [Commits](https://gitlab.com/kicad/kicad-ci/kicad-cli-docker/commits/main)
    ---
    updated-dependencies:
    - dependency-name: kicad/kicad
    dependency-version: 9.0.4
    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
2025-11-02 Bump kicad/kicad from 9.0.4 to 9.0.6 (#45)
    Bumps [kicad/kicad](https://gitlab.com/kicad/kicad-ci/kicad-cli-docker) from 9.0.4 to 9.0.6.
    dependency-version: 9.0.6
    dependency-type: direct:production
    update-type: version-update:semver-patch
    ...
    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
2025-11-02 Bump panic-probe from 0.3.2 to 1.0.0 (#43)
    Bumps [panic-probe](https://github.com/knurling-rs/defmt) from 0.3.2 to 1.0.0.
    - [Release notes](https://github.com/knurling-rs/defmt/releases)
    - [Changelog](https://github.com/knurling-rs/defmt/blob/main/CHANGELOG.md)
    - [Commits](https://github.com/knurling-rs/defmt/compare/panic-probe-v0.3.2...defmt-v1.0.0)
    - dependency-name: panic-probe
    dependency-version: 1.0.0
    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
2026-01-17 Fix buffer overrun in gnss-i2c-stream.rs (#58)
    [gnss-i2c-stream.rs, gnss-uart-pipe.rs]
2026-03-08 Bump kicad/kicad from 9.0.6 to 9.0.7
    Bumps [kicad/kicad](https://gitlab.com/kicad/kicad-ci/kicad-cli-docker) from 9.0.6 to 9.0.7.
    dependency-version: 9.0.7
    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
2026-03-08 Re-save project with KiCad 9.0.7
    [gnss-7-seg-clock.kicad_pcb, gnss-7-seg-clock.kicad_sch]
2026-04-04 Bump kicad/kicad from 9.0.7 to 10.0.0 (#72)
    * Bump kicad/kicad from 9.0.7 to 10.0.0
    Bumps [kicad/kicad](https://gitlab.com/kicad/kicad-ci/kicad-cli-docker) from 9.0.7 to 10.0.0.
    dependency-version: 10.0.0
    update-type: version-update:semver-major
    * Re-save project with KiCad 10.0.0
    ---------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
    [gnss-7-seg-clock.kicad_pcb, gnss-7-seg-clock.kicad_sch]
2026-05-03 Bump kicad/kicad from 10.0.0 to 10.0.1 (#80)
    Bumps [kicad/kicad](https://gitlab.com/kicad/kicad-ci/kicad-cli-docker) from 10.0.0 to 10.0.1.
    dependency-version: 10.0.1
    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
2026-06-06 Bump kicad/kicad from 10.0.1 to 10.0.2 (#85)
    Bumps [kicad/kicad](https://gitlab.com/kicad/kicad-ci/kicad-cli-docker) from 10.0.1 to 10.0.2.
    dependency-version: 10.0.2
    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
2026-07-02 Bump kicad/kicad from 10.0.2 to 10.0.4 (#90)
    Bumps [kicad/kicad](https://gitlab.com/kicad/kicad-ci/kicad-cli-docker) from 10.0.2 to 10.0.4.
    dependency-version: 10.0.4
    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
2026-08-02 Bump kicad/kicad from 10.0.4 to 10.0.5 (#93)
    Bumps [kicad/kicad](https://gitlab.com/kicad/kicad-ci/kicad-cli-docker) from 10.0.4 to 10.0.5.
    dependency-version: 10.0.5
    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
2026-10-02 Bump kicad/kicad from 10.0.5 to 10.0.6 (#104)
    Bumps [kicad/kicad](https://gitlab.com/kicad/kicad-ci/kicad-cli-docker) from 10.0.5 to 10.0.6.
    dependency-version: 10.0.6
    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
2026-11-03 Bump kicad/kicad from 10.0.6 to 10.0.8 (#111)
    Bumps [kicad/kicad](https://gitlab.com/kicad/kicad-ci/kicad-cli-docker) from 10.0.6 to 10.0.8.
    dependency-version: 10.0.8
    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

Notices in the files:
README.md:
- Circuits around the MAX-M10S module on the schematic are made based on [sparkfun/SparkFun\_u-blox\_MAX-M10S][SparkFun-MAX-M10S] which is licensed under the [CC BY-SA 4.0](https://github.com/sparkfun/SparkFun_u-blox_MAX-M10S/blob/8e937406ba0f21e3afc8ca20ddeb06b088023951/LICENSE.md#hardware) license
